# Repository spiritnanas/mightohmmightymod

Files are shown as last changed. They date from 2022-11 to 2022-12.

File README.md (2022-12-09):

To Do:
- Add real time clock
- Add in device calibration settings
- Improve graphing screens
- Custom PCB for all non MightyOhm components
- Built in Lithium Ion battery that powers both Pi and Mighty Ohm
- Shielding + Geiger tube cover to optionally block beta particals

# mightohmmightymod
A Pi Pico Mod for the MightOhm Geiger Counter Kit

Parts:

1) https://www.amazon.com/gp/product/B072Q2X2LL/ref=ppx_yo_dt_b_asin_title_o09_s00?ie=UTF8&psc=1
2) https://www.amazon.com/gp/product/B09DPMQ1F3/ref=ppx_yo_dt_b_asin_title_o08_s00?ie=UTF8&psc=1
3) https://www.amazon.com/gp/product/B00NAY2NAI/ref=ppx_yo_dt_b_asin_title_o02_s00?ie=UTF8&psc=1
4) https://www.amazon.com/gp/product/B093PJ2NJZ/ref=ppx_yo_dt_b_asin_title_o00_s00?ie=UTF8&psc=1
5) https://www.amazon.com/gp/product/B08RMQP6YP/ref=ppx_yo_dt_b_asin_title_o00_s00?ie=UTF8&th=1
6) https://www.amazon.com/gp/product/B07CKLNR2T/ref=ppx_yo_dt_b_asin_title_o02_s00?ie=UTF8&psc=1
7) https://mightyohm.com/blog/products/geiger-counter/

Step 1) Connect all components as discussed in the pinout document under the Documentation section. I used the item under the 5th Amazon link to make detachable cables for easy component replacement. To connect the Pi to the MightyOhm I used a custom cable, made using the below steps:

      1) Cut a GPIO jumper cable, leaving about 3/4" of wire. You want to use the female side of the cable for this purpose. 
      2) Remove the plastic housing from the connector using side cutters. Be careful here to avoid cutting the wire inside.
      3) Use heatshrink around the remaining metal connector. 
      4) Strip about 1/8" of the wire from the GPIO cable.
      5) Now, using the cable kit (item 6 on the purchase list), create a 2 wire cable, attaching both a female end and male end. 
      6) Cut this cable in half.
      7) Add heat shrink to one half of the cable.
      8) Solder one end of the newely cut in half cable to the GPIO cable.
      9) Solder the remaining cable to the Pi Pico, making reference to the pinout documentation in the Documentation section. 

Step 2) Print all files in the STL folder.

Step 3) Attach components from step 1 to the midplate.

Step 4) Set up Pi Pico for use with MicroPython. I used Thonny. Simply install Thonny. Once installed, plug the Pi in with the boot select button held down. Thonny should suggest the installation of the required files for MicroPython onto the Pi. 

Step 5) Use Thonny to copy the main.py, sdcard.py and the lib folder to the Pi Pico. 

Step 6) Power on the Pi Pico, it should boot up and load the application. 

Step 7) Once you test everything, use #4-40x3/4" to affix the pieces together. The printed components screw into the standoffs included in the MightyOhm kit. 

Demo Videos:

https://www.youtube.com/shorts/H37LoZpWwPw

https://www.youtube.com/watch?v=6j20wASLf7Y

Reference Pictures:









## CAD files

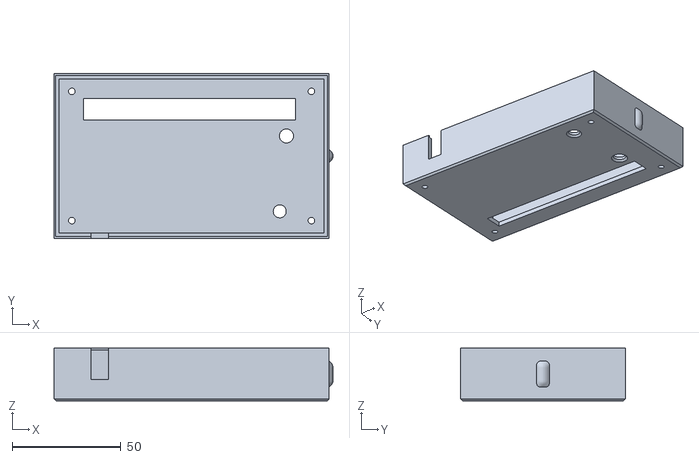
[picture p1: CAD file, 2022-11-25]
STLFiles/BottomCase.stl
128.5 x 75.8 x 24.4

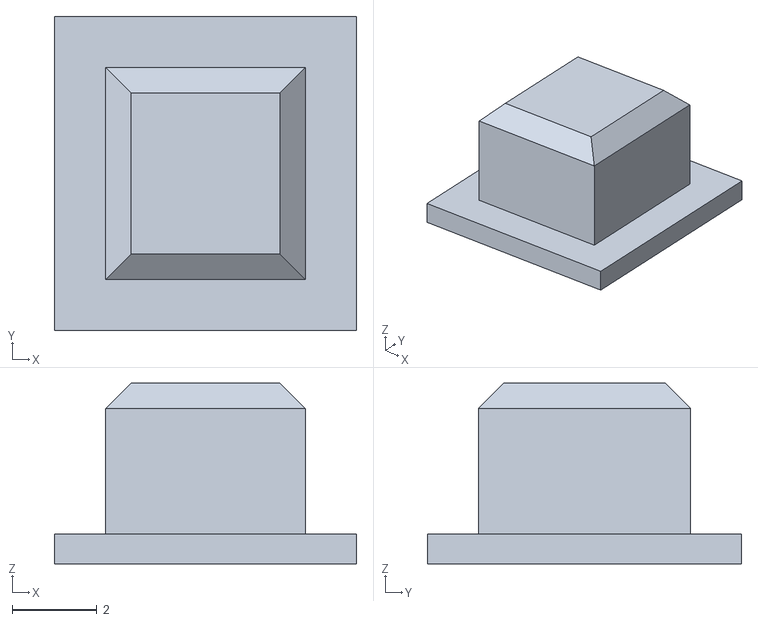
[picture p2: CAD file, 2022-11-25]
STLFiles/Button.stl
7.11 x 7.40 x 4.25

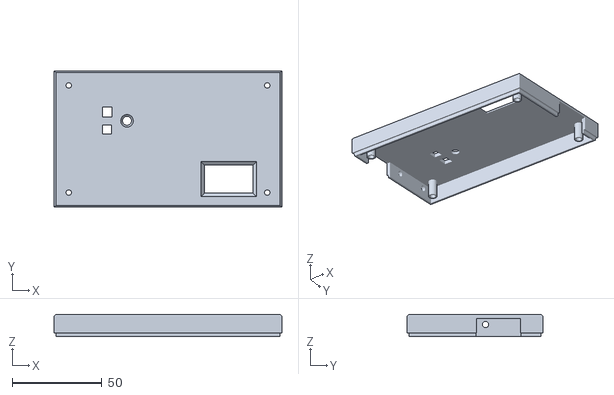
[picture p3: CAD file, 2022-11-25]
STLFiles/TopCase.stl
126.8 x 75.8 x 12.4

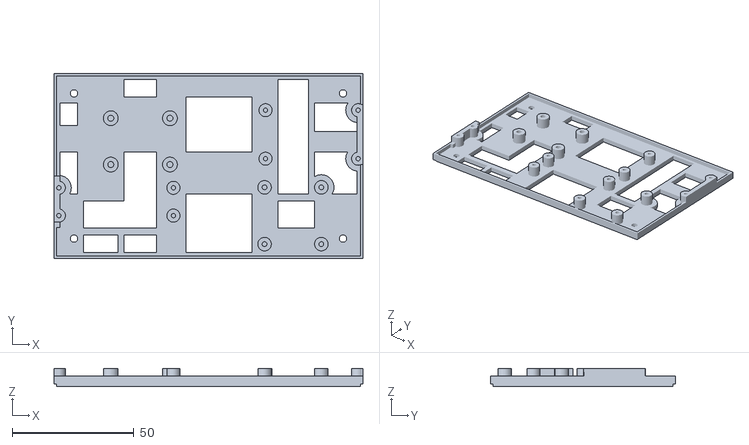
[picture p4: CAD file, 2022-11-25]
STLFiles/Midplate.stl
126.8 x 75.8 x 7.40

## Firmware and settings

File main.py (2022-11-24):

# Display Image & text on I2C driven ssd1306 OLED display 
from machine import Pin, I2C, SPI
from ssd1306 import SSD1306_I2C
from time import sleep
import utime
from math import floor
import sdcard
import os
import _thread
from micropython import mem_info

sleep(1)

#sLock = _thread.allocate_lock()

counts = 0 #geiger counts registered 
cumUsv = 0 #Cumulative micro servets
mainMenuReset = False #flagged in various functions. When true, the program will return to the main menu. 
downButton = False #changed by function attached to an interupt pin. used when navigating menues. 
upButton = False #changed by function attached to an interupt pin. used when navigating menues. 
centerButton = False #changed by function attached to an interupt pin. used when navigating menues. 
leftButton = False #changed by function attached to an interupt pin. used when navigating menues. 
navCursor = 1 #Keeps track of where you are in menus. Navframes, which are used to create menues, work in groups of 4.
#The navCursor keeps track of which menu item is sellected.

#Init SD Card
spi=SPI(1,baudrate=9600,sck=Pin(10),mosi=Pin(11),miso=Pin(12)) #12=MISO,11=MOSI,10=SCK
try:
    sd=sdcard.SDCard(spi,Pin(13)) #13 is chip select (cs) pin
    vfs=os.VfsFat(sd)
    os.mount(sd,'/sd')
    print(os.listdir('/sd'))

except:
        print("SD Card Not Installed")
    



#Hardware Interupts
def countCpm(p):                                        #Triggered by interupt pin, counts per minute from geiger counter
    global counts
    counts += 1

def mainMenu(p):
    global mainMenuReset
    mainMenuReset = True
    
def down(p):
    global downButton
    downButton = True

def up(p):
    global upButton
    upButton = True
    
def center(p):
    global centerButton
    centerButton = True
    
def left(p):
    global leftButton
    leftButton = True
    
interuptPin0 = machine.Pin(0, machine.Pin.IN, machine.Pin.PULL_UP)
interuptPin0.irq(trigger=interuptPin0.IRQ_FALLING, handler=countCpm)

#reset
interuptPin4 = machine.Pin(4, machine.Pin.IN, machine.Pin.PULL_UP)
interuptPin4.irq(trigger=interuptPin0.IRQ_RISING, handler=mainMenu)

 #down
interuptPin6 = machine.Pin(7, machine.Pin.IN, machine.Pin.PULL_UP)
interuptPin6.irq(trigger=interuptPin0.IRQ_RISING, handler=down)

 #up
interuptPin8 = machine.Pin(6, machine.Pin.IN, machine.Pin.PULL_UP)
interuptPin8.irq(trigger=interuptPin0.IRQ_RISING, handler=up)


interuptPin19 = machine.Pin(19, machine.Pin.IN, machine.Pin.PULL_UP)#Center
interuptPin19.irq(trigger=interuptPin0.IRQ_RISING, handler=center)

#left
interuptPin7 = machine.Pin(8, machine.Pin.IN, machine.Pin.PULL_UP)#Center
interuptPin7.irq(trigger=interuptPin0.IRQ_RISING, handler=left)

#Display setup
WIDTH  = 128                                            # oled display width
HEIGHT = 64                                             # oled display height
i2c = I2C(1, sda=Pin(2), scl=Pin(3), freq=400000)       # Init I2C using pins GP8 & GP9 (default I2C0 pins)
print("I2C Address      : "+hex(i2c.scan()[0]).upper()) # Display device address
print("I2C Configuration: "+str(i2c))                   # Display I2C config
oled = SSD1306_I2C(WIDTH, HEIGHT, i2c)                  # Init oled display
oled.fill(0)                                            # Clear the oled display in case it has junk on it.


def getTimeStamp():
    rtc = machine.RTC()
    tStamp = rtc.datetime()
    timeString="%04d-%02d-%02d_%02d-%02d-%02d"%(tStamp[0:3] + tStamp[4:7])
    return timeString

def collectData(period):
    global counts
    global cumUsv
    global mainMenuReset
    global centerButton
    counts = 0
    x = 0
    while (x < period * 2): 
        sleep(period / (period * 2))
        x += 1
        if mainMenuReset == True:
            mainMenuReset = False
            return False
    cpm = counts * (60/period)
    usvh = cpm * .0057
    cumUsv += (usvh / ((60 * 60) / period))
    return [period,cpm,str(counts),usvh,getTimeStamp(),cumUsv]
        

def sdCardOutput(fileName,lineToWrite):
    try:
        file = open(fileName,"a")
        file.write(lineToWrite)
        file.close()
    except:
        print("SD Card Not Installed")

def initCsvHeader(fileName, csvHeader):
    #Creates CSV file header.
    sdCardOutput(fileName, csvHeader)

def dataLine(cDO):
    #Formats the data line for enttry into csv (ex. 5, 0.0, '0', 0.0, '2022-05-23_22-57-56', 0.0,)
    return("{},{},{},{},{},{},".format(cDO[0],cDO[1],cDO[2],cDO[3],cDO[4],cDO[5]))

class dataCollectionObj:
    def __init__(self, period, logType, infinite, iterations):
        self.period = period
        self.logType = logType
        self.infinite = infinite
        self.iterations = iterations
        
    def dataLoggingDisplayOut(self,runningAvg,data,period,itterations = 1,curItteration = 1):
        oled.fill(0)
        if itterations != 1:
            curX = floor(((curItteration/itterations)) * 128)
            oled.fill_rect(0, 0, curX, 8, 1)
        else:
            oled.fill_rect(0, 4, 128, 12, 1)
            oled.text("Cont. Metering",4, 6,0)

        oled.text("{:.3f} uSv/h".format(data[3]),0,16)
        oled.text("{:.3f} Cum. uSv".format(data[5]),0,24)
        oled.text("{:.3f} Last 4 Avg uSv/h".format(runningAvg),0,34)
        oled.text("Reset x2 to exit.",0,56)
        #oled.text("Menu",0,56)
        oled.show()

    def logTimed(self):
        global mainMenuReset
        #Clears the display and informs the user that the data collection has started
        oled.fill(0)
        oled.text("Data collection",5,16)
        oled.text("started!",5,26)
        oled.text("Please wait " + str(self.period) + "s",5,36)
        oled.show()
        #Create CSV file with header
        header = "avgPeriod,cpm,counts,usvh,timestamp,cumUsvSinceStart,\n"
        fileOut = "/sd/radCollect_" + getTimeStamp() + ".csv"
        initCsvHeader(fileOut, header)
        x = 0
        runningAvg = [0,0,0,0]
        runningAvgCounter = 0
        #Iterations is a property of the dataCollectionObj that defines how many itterations
        #a data logging session should run for.
        while x < self.iterations:
            x += 1
            #mainMenuReset is set by an interupt.
            if mainMenuReset == True:
                break
            #Checks to see if the class propery infinite is True. If it is, this while loop will run till broken,
            #collecting data infinitly. 
            if self.infinite:
                x = 1        
            data = collectData(self.period)
            #This checks to see if the mainMenuReset has been trigged mid collection cycle, this is to provide faster
            #UI response when buttons are pressed to reset. 
            if data == False:
                break
            
            #Calculates a running average by keeping track of and averaging the last four values. 
            runningAvg[runningAvgCounter] = data[3]
            runningAvgCounter += 1
            if runningAvgCounter > 2:
                runningAvgCounter = -1
            runningAvgRes = 0
            for y in range(0, len(runningAvg)):
                runningAvgRes += runningAvg[y]
            runningAvgRes = runningAvgRes/len(runningAvg)
            print(runningAvgRes)
            #Puts the result of the latest data collection period on the screen
            self.dataLoggingDisplayOut(runningAvgRes,data,self.period)            
            #Converts the data to CSV format
            data = str(data)
            data = data[1:(len(data)-1)] + ",\n"
            print(data)
            #Writes the data to the SD Card.
            sdCardOutput(fileOut,str(data))
            
        while(mainMenuReset == False):
           continue 
        
        return "resetDisplay"

class dataGraphObj:
#This function collects and displays data in a bar chart style graph.
    def __init__(self, period, logType, infinite, iterations):
        self.period = period
        self.logType = logType
        self.infinite = infinite
        self.iterations = iterations
        
    def graphDisplayOut(self,data,period,graphCoords):
        oled.fill(0)
        oled.fill_rect(0, 0, 128, 12, 1)
        oled.text("Graph|",0, 2,0)
        oled.text("{:.3f}uSvh".format(data[3]),50,2,0)
        for x in graphCoords:
            oled.fill_rect(x[0],x[1],x[2],x[3],1)
             
        oled.show()

    def graphData(self):
        global mainMenuReset
        #Clears the display and informs the user that the data collection has started
        oled.fill(0)
        oled.text("Data collection",5,16)
        oled.text("started!",5,26)
        oled.text("Please wait " + str(self.period) + "s",5,36)
        oled.show()
        x = 0
        
        screenSizeX = 128
        screenSizeY = 64
        screenDivisions = 32
        divisionSize = int(floor(screenSizeX / screenDivisions))
        
        graphCoords = []
        
        while True:
            #mainMenuReset is set by an interupt.
            if mainMenuReset == True:
                break       
            data = collectData(self.period)
            #This checks to see if the mainMenuReset has been trigged mid collection cycle, this is to provide faster
            #UI response when buttons are pressed to reset. 
            if data == False:
                break
            #moves the bars accross the screen by adjusting the X value by the size of the screen divided by the chosen resolution of the bar graph
            #this is stored in "screenDivisions". It also pops off the oldest entry and appends the latest. 
            if len(graphCoords) >= screenDivisions:
                try:
                    graphCoords.pop(0)
                except:
                    print("List is empty!")
                graphCoords.append([screenSizeX - divisionSize, screenSizeY - int(data[2]),divisionSize,screenSizeY])
            else:
                graphCoords.append([screenSizeX - divisionSize, screenSizeY - int(data[2]),divisionSize,screenSizeY])
            for x in range(0,len(graphCoords)-1):
                graphCoords[x][0] = graphCoords[x][0] - divisionSize
                #graphCoords[x][2] = graphCoords[x][2] - divisionSize
            
            print(graphCoords)
            
            #Puts the result of the latest data collection period on the screen
            self.graphDisplayOut(data,self.period,graphCoords)            
            #Converts the data to CSV format
            data = str(data)
            data = data[1:(len(data)-1)] + ",\n"
            print(data)
        
        while(mainMenuReset == False):
           continue 
        return "resetDisplay"    
    
#UI Classes
    
class uiObject:
    def __init__(self, uiType, sizeX, sizeY, name,):
        #uiObject is intended to be an abstract class that is the root of the UI section.  
        self.uiType = uiType
        self.sizeX = sizeX
        self.sizeY = sizeY
        self.name = name
        
class button(uiObject):
        #button objects are intended to be UI elements that can be interacted with. 
    def __init__(self, buttonType, pressed,uiType, sizeX, sizeY, name):
        self.buttonType = buttonType
        self.pressed = pressed
        
        uiObject.__init__(self,uiType, sizeX, sizeY, name)

class navFrame(uiObject):
        #navFrames contain collections of navPanes. navPanes are the individual menus, navFrames group them together
        #into menues that can be scrolled through. 
    def __init__(self,uiType, sizeX, sizeY, name, menu):
        self.name = name
        self.menu = menu
        
        uiObject.__init__(self,uiType, sizeX, sizeY, name)
        
    def mainMenuResetRender(self):
        #This function is designed to be used with the reset interupt and will return the user to
        #the menu after having clicking on an object in the menu upon clicking the reset button. 
        global mainMenuReset
        mainMenuReset = False
        oled.fill(0)
        renderMainMenu(self.menu,-1, 1)
    def render(self):
        #This contains the logic to render the navFrames on screen. 
        global upButton
        global downButton
        global mainMenuReset
        global centerButton
        global leftButton
        
        #Zeros out the screen to remove previously drawn frame
        oled.fill(0)
        #navPane buttons are stored in an array. This navCursor defines which one is currently highlighted. 
        lnavCursor = 1
        #resets buttons to false state. This is because the interupts used to navigate this menu change the values of
        #the global variables used for navigation, so when this is called again to render new information, it does not
        #count as another button "press".
        centerButton = False
        leftButton = False
        while centerButton != False:
            continue
        renderMainMenu(self.menu,1)
        self.menu[1].highlighted = True
        self.menu[1].drawObj()
        self.menu[1].highlighted = False
        
        while (True):
            sleep(.05)
            if (upButton == True) and (lnavCursor > 1):
                lnavCursor -= 1
                self.menu[lnavCursor].up(self.menu, lnavCursor)
                
                
            elif (downButton == True) and (lnavCursor < (len(self.menu) -1)):
                lnavCursor += 1
                self.menu[lnavCursor].down(self.menu, lnavCursor)
                
                
            elif (centerButton == True):
                centerButton = False
                if(isinstance(self.menu[lnavCursor].link, navFrame) and self.menu[lnavCursor].link.uiType == "navFrame"):
                    self.menu[lnavCursor].link.render()
                elif(isinstance(self.menu[lnavCursor].link,dataCollectionObj)):
                    if self.menu[lnavCursor].link.logTimed() == "resetDisplay":
                        self.mainMenuResetRender()
                elif(isinstance(self.menu[lnavCursor].link,dataGraphObj)):
                    if self.menu[lnavCursor].link.graphData() == "resetDisplay":
                        self.mainMenuResetRender()
                        
                
            elif(centerButton == True):
                centerButton = False
            
            elif(leftButton == True and self.name != "Main Menu"):
                break
            
            if(leftButton == True):
                lnavCursor = 1
                renderMainMenu(self.menu,1)
                self.menu[1].highlighted = True
                self.menu[1].drawObj()
                self.menu[1].highlighted = False
                leftButton = False

            oled.show()

            
        
class navPane(uiObject):
    #navPanes are the individual menu objects. These can be highlighted/selected or not. 
    def __init__(self, highlighted,uiType, sizeX, sizeY, name, contentText, locX, link = False, backLink = False):
        self.highlighted = highlighted
        self.contentText = contentText
        self.locX = locX
        self.link = link
        uiObject.__init__(self,uiType, sizeX, sizeY, name)
    
    #Draws the navPane with the given parameters.
    def drawObj(self):
        if(self.highlighted == True):
            oled.fill_rect(0, self.locX, self.sizeX, self.sizeY, 1)
            oled.text(self.contentText,4, self.locX + 2,0)
        else:
            oled.rect(0, self.locX, self.sizeX, self.sizeY, 1)
            oled.text(self.contentText,4, self.locX + 2)
            
    def up(self, menu, lnavCursor):
        #If the global upButton variable is True this calls "renderMenu"
        global upButton
        self.renderMenu("up",menu, lnavCursor)
        upButton = False
        menu[lnavCursor].highlighted = True
        menu[lnavCursor+1].highlighted = False
        menu[lnavCursor].drawObj()
        menu[lnavCursor].highlighted = False
    def down(self, menu, lnavCursor):
        global downButton
        self.renderMenu("down",menu, lnavCursor)
        downButton = False
        menu[lnavCursor].highlighted = True
        menu[lnavCursor-1].highlighted = False
        menu[lnavCursor].drawObj()
        menu[lnavCursor].highlighted = False
        
    def renderMenu(self,direction,menu, lnavCursor):
        #Render menu calls renderMainMenu.
        if direction == "up":
            renderMainMenu(menu,lnavCursor)
        if direction == "down":
            renderMainMenu(menu,lnavCursor)
       



def renderMainMenu(menu,toSkip,curCursor = -1):
    #This function clears the display, then if the menu objects get evaluated for rendering.
    #It checks to see if the 
    #If the curCursor is not provided (ie. the value is -1) it is skipped. 
    oled.fill(0)
    for x in range(0, len(menu)):
        if ((menu[x].uiType == "MenuOption") and x != toSkip):
            menu[x].drawObj()
            if curCursor != -1:
                menu[curCursor].highlighted = True
                menu[curCursor].drawObj()
                menu[curCursor].highlighted = False

                
    oled.show()
    






def main():
    #UI Objects
    
    #TimedMeterMenuObjects
    logFiveSec = dataCollectionObj(5, "timedLog", False, 3)
    logTenSec = dataCollectionObj(10, "timedLog", False, 3)
    logSixtySec = dataCollectionObj(30, "timedLog", False, 3)
    logFiveMin = dataCollectionObj(300, "timedLog", False, 3)
    
    #ConstantMeteringObjects
    logCont = dataCollectionObj(5, "contLog", True, 10)
    
    graphData = dataGraphObj(1, "contLog", True, 10)
    
    #TimedMeterMenu
    timedMenu = navPane(highlighted = True,uiType = "MenuOption",sizeX = 128, sizeY = 12, name = "Timed Metering", contentText = "Timed Metering", locX = 4)
    fiveSecAvg = navPane(highlighted = False,uiType = "MenuOption",sizeX = 128, sizeY = 12, name = "5 Sec Avg", contentText = "5 Sec Avg", locX = 15, link = logFiveSec)
    tenSecAvg = navPane(highlighted = False,uiType = "MenuOption",sizeX = 128, sizeY = 12, name = "10 Sec Avg", contentText = "10 Sec Avg", locX = 26, link = logTenSec)
    thirtySecAvg = navPane(highlighted = False,uiType = "MenuOption",sizeX = 128, sizeY = 12, name = "30 Sec Avg", contentText = "30 Sec Avg", locX = 37, link = logSixtySec)
    minAvg = navPane(highlighted = False,uiType = "MenuOption",sizeX = 128, sizeY = 12, name = "5 Min Avg", contentText = "5 Min Avg", locX = 48, link = logFiveMin)

    timedUiArr = [timedMenu,fiveSecAvg,tenSecAvg,thirtySecAvg,minAvg]
    timedMenu = navFrame("navFrame", 128, 64, "Timed Menu", timedUiArr)

    #MAIN MENU
    mainMenu = navPane(True,"MenuOption",128,12,"Main Menu", "Main Menu", 4)
    constantMeteringMenuOption = navPane(False,"MenuOption",128,12,"constantMeteringMenuOption", "Const. Metering", 15, logCont)
    timedMeterOptions = navPane(False,"MenuOption",128,12,"timedMeterOptions", "Timed Metering", 26, timedMenu)
    graphData = navPane(False,"MenuOption",128,12,"placeholder", "Graph",37, link = graphData)
    setup = navPane(False,"MenuOption",128,12,"SetupMenu", "Setup - TBD",48)


    uiArr = [mainMenu, constantMeteringMenuOption, timedMeterOptions, graphData, setup]
    mainMenu = navFrame("navFrame", 128, 64, "Main Menu", uiArr)
    #renderMainMenu(uiArr)
    

    mainMenu.render()
    #navArray(uiArr)
    #navArray(timedUiArr)
    
   

main()
